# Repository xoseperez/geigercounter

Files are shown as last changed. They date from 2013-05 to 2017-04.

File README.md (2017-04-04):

# Geiger Counter

Geiger counter based on the [Geiger Counter Radiation Detector DIY Kit](http://www.rhelectronics.net/store/radiation-detector-geiger-counter-diy-kit-second-edition.html "Geiger Counter Radiation Detector DIY Kit") from [Radio Hobby Store](http://www.rhelectronics.net/store/ "RH electronics store").

You can read about this project in my blog: [Geiger Counter](http://tinkerman.eldiariblau.net/geiger-counter/ "Geiger Counter").

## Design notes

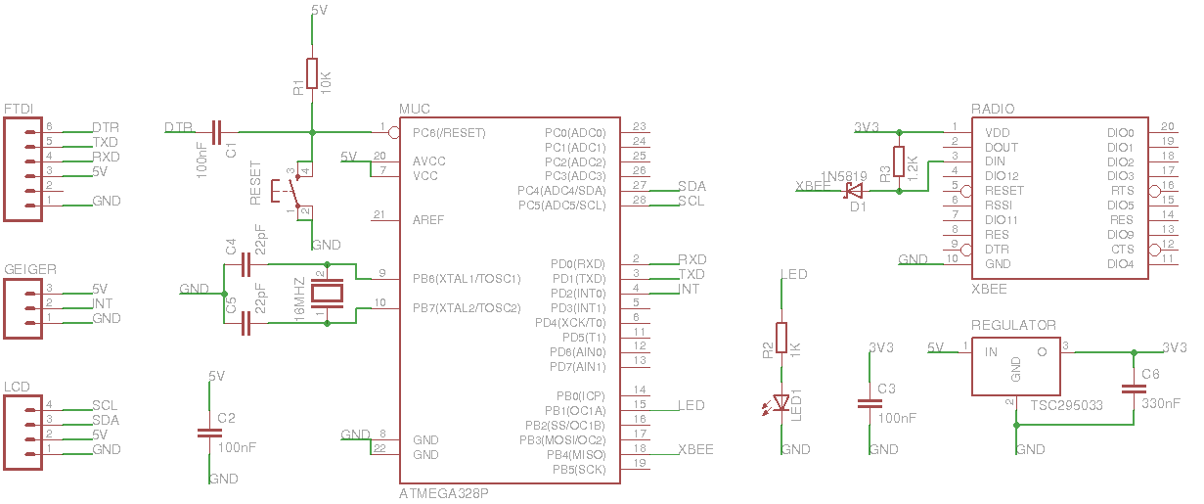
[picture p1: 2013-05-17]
schema/schema.png

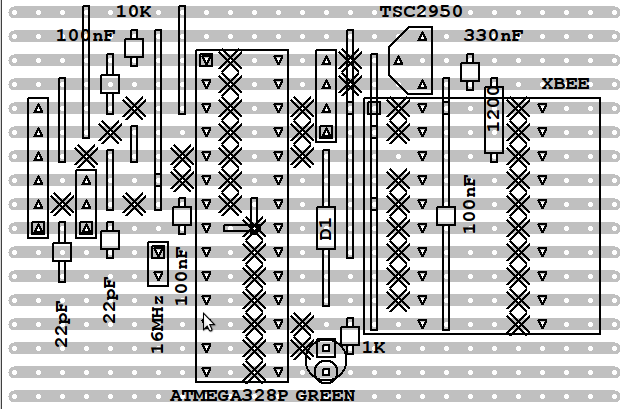
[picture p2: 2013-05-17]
schema/stripboard.png

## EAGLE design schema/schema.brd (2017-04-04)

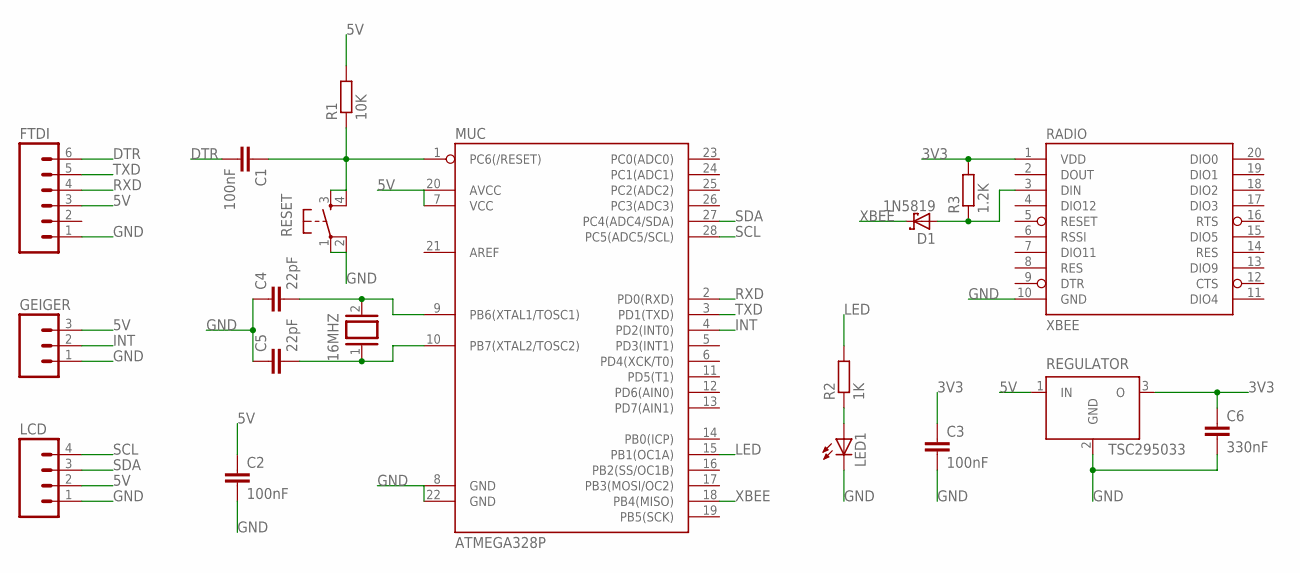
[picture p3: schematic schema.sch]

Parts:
16MHZ: XTAL/S; QS
C1, C2, C3: 100nF; C025-025X050
C4, C5: 22pF; C025-025X050
C6: 330nF; C025-025X050
D1: 1N5819; DO41-7.6
FTDI: M06SIP; 1X06
GEIGER: M03PTH; 1X03
LCD: M04PTH; 1X04
LED1: LED3MM
MUC: ATMEGA328P; DIL28-3
R1: 10K; 0207/10
R2: 1K; 0207/10
R3: 1.2K; 0207/10
RADIO: XBEE; XBEE-1
REGULATOR: TSC295033; TO92
RESET: TAC_SWITCHPTH; TACTILE-PTH

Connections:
3V3: C3.1, C6.1, R3.2, RADIO.1 (VDD), REGULATOR.3 (O)
5V: C2.1, FTDI.3, GEIGER.3, LCD.2, MUC.7 (VCC), MUC.20 (AVCC), R1.2, REGULATOR.1 (IN)
DTR: C1.2, FTDI.6
GND: C2.2, C3.2, C4.1, C5.1, C6.2, FTDI.1, GEIGER.1, LCD.1, LED1.K (C), MUC.8 (GND), MUC.22 (GND), RADIO.10 (GND), REGULATOR.2 (GND), RESET.1, RESET.2
INT: GEIGER.2, MUC.4 (PD2(INT0))
LED: MUC.15 (PB1(OC1A)), R2.2
unnamed: C1.1, MUC.1 (PC6(/RESET)), R1.1, RESET.3, RESET.4
unnamed: 16MHZ.2, C4.2, MUC.9 (PB6(XTAL1/TOSC1))
unnamed: 16MHZ.1, C5.2, MUC.10 (PB7(XTAL2/TOSC2))
unnamed: D1.A, R3.1, RADIO.3 (DIN)
unnamed: LED1.A, R2.1
RXD: FTDI.4, MUC.2 (PD0(RXD))
SCL: LCD.4, MUC.28 (PC5(ADC5/SCL))
SDA: LCD.3, MUC.27 (PC4(ADC4/SDA))
TXD: FTDI.5, MUC.3 (PD1(TXD))
XBEE: D1.C, MUC.18 (PB4(MISO))

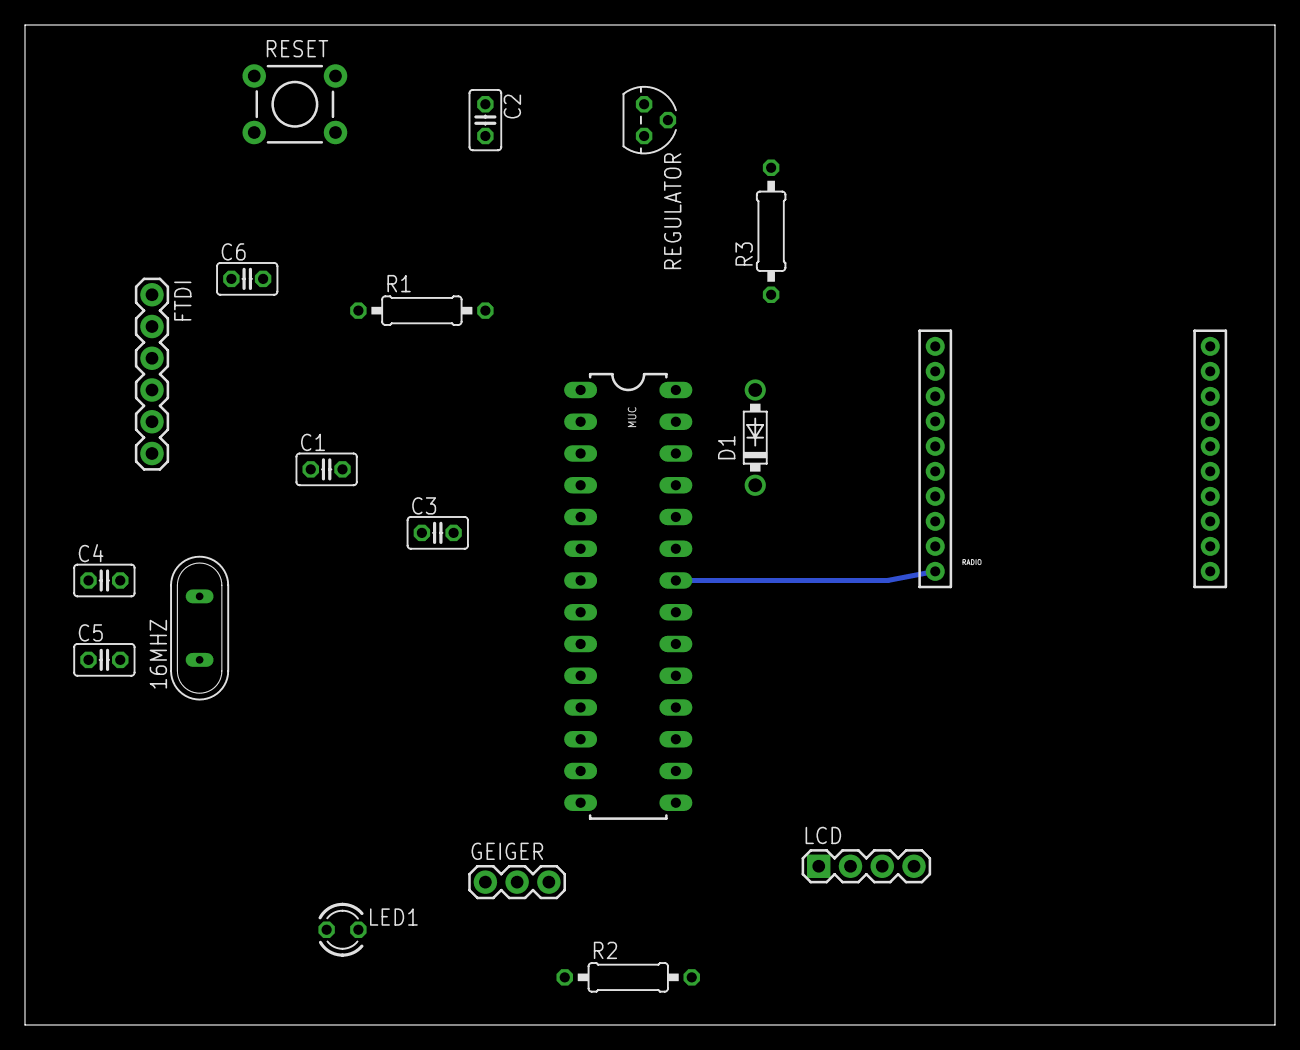
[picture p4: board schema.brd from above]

Board: 2 copper layers, 100.0 x 80.0 mm, 19 parts (0 on the bottom side), 16 nets.

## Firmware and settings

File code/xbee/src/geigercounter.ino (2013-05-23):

/*

  Geiger-Muller Counter
  Copyright (C) 2013 by Xose Pérez <xose dot perez at gmail dot com>

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
*/

#include <SoftwareSerial.h>
#include <Wire.h>
#include <LiquidCrystal_I2C.h>

// ===========================================
// Configuration
// ===========================================

// pin definitions
#define GEIGER_INTERRUPT 0
#define DEBUG_PIN 9
#define XBEE_PIN 12

// count data for a whole minute (60000 milliseconds)
// split into 10 chunks of 6 seconds each
#define PERIOD_LENGTH 60000
#define UPDATES_PER_PERIOD 10

// conversion factor from CPM to uSv/h based on data from Libellium for the SBM-20 tube
// http://www.cooking-hacks.com/index.php/documentation/tutorials/geiger-counter-arduino-radiation-sensor-board
#define CPM_TO_USVH 0.0057


// ===========================================
// Globals
// ===========================================

// pulses in the current subperiod
volatile unsigned long pulses = 0;

// stores the pulses for a set of 6 seconds periods
unsigned long ring[UPDATES_PER_PERIOD] = {0};

// pointer to the next cell in the ring to update
byte pointer = 0;

// keeps the sum of counts for the ring
unsigned long cpm = 0;

// time of the next update
unsigned long next_update = 0;

// during the first minute after a reset, the display shows a "warming up" message
boolean warmup = true;

// serial link to the radio
SoftwareSerial xbee(0, XBEE_PIN);

// LCD management
// Thanks to Riva for pointing out the wrong pin order
// http://arduino.cc/forum/index.php?topic=164722.0
// 0 -> RS
// 1 -> RW
// 2 -> EN
// 3 -> LED
// 4- > D4
// 5 -> D5
// 6 -> D6
// 7 -> D7
//
// Constructor with backlight control
// LiquidCrystal_I2C(uint8_t lcd_Addr, uint8_t En, uint8_t Rw, uint8_t Rs,.
//                  uint8_t d4, uint8_t d5, uint8_t d6, uint8_t d7,
//                  uint8_t backlighPin, t_backlighPol pol);
LiquidCrystal_I2C lcd(0x20, 2, 1, 0, 4, 5, 6, 7, 3, POSITIVE);

// ===========================================
// Interrupt routines
// ===========================================

/**
 * pulse
 *
 * Called on every LOW-to-HIGH transition on the 
 * GEIGER_INTERRUPT pin. It updates the current count.
 *
 * @return void
 */
void pulse() {
    ++pulses;
}

// ===========================================
// Methods
// ===========================================

/**
 * update
 *
 * Updates the ring and CPM count.
 * Shows the results on the LCD and sends them through radio every minute.
 *
 * @return void
 */
void update() {

    // calculate the moving sum of counts
    cpm = cpm - ring[pointer] + pulses;

    // store the current period value
    ring[pointer] = pulses;

    // reset the interrupt counter
    pulses = 0;

    // move the pointer to the next position in the ring
    pointer = (pointer + 1) % UPDATES_PER_PERIOD;

    // calculate the uSv/h 
    float usvh = cpm * CPM_TO_USVH;

    // show data in LCD
    if (warmup) {

        lcd.setCursor(0, 1);
        lcd.print(cpm, DEC);

    } else {

        lcd.clear();
        lcd.print(F("CPM:   "));
        lcd.print(cpm, DEC);
        lcd.setCursor(0, 1);
        lcd.print(F("uSv/h: "));
        lcd.print(usvh, 3);

    }

    // send data through radio everytime the ring loops back
    if (pointer == 0) {

        digitalWrite(DEBUG_PIN, HIGH);

        xbee.print(F("cpm:"));
        xbee.println(cpm, DEC);
        delay(20);
        xbee.print(F("usvh:"));
        xbee.println(usvh, 3);
        delay(20);

        digitalWrite(DEBUG_PIN, LOW);

        // finish the warmup after the first full period
        warmup = false;

    }

}

/**
 * setup
 *
 * Configures pins, LCD and XBee. Sets up interrups.
 *
 * @return void
 */
void setup() {

    pinMode(DEBUG_PIN, OUTPUT);
    digitalWrite(DEBUG_PIN, LOW);

    // initilize LCD and XBEE
    lcd.begin(16,2);
    lcd.setBacklight(BACKLIGHT_ON);
    xbee.begin(9600);
    delay(500);

    // show warmup message
    lcd.home();
    lcd.print(F("Warming up..."));

    // send welcome message
    xbee.println(F("status:1"));

    // allow pulse to trigger interrupt on rising
    attachInterrupt(GEIGER_INTERRUPT, pulse, RISING);

    // calculate next update
    next_update = millis() + PERIOD_LENGTH / UPDATES_PER_PERIOD;

}

/**
 * loop
 *
 * Continuously checks for the next update time.
 *
 * @return void
 */
void loop() {

    // check if I have to update the info
    if (millis() > next_update) {
        next_update = millis() + PERIOD_LENGTH / UPDATES_PER_PERIOD;
        update();
    }

}

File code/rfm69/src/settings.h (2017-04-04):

// -----------------------------------------------------------------------------
// Settings
// -----------------------------------------------------------------------------

// This node ID, should be unique in the same network
#define NODEID              13

// Gateway ID that will receive the messages from this node
#define GATEWAYID           1

// Network ID, only nodes from the same network see each other
#define NETWORKID           164

// Frequency of the radio, should match your radio module and
// comply with your country legislation
#define FREQUENCY           RF69_868MHZ

// Encription key, shared between the node and the gateway
#define ENCRYPTKEY          "fibonacci0123456"

// If you are using a RFM69HW or RFM69HCW module set this to 1 to
// transmitt to extra power (and extra battery drainage)
#define IS_RFM69HW          0

// Set the target RSSI for Auto Transmission Control feature.
// The module will modify it's transmitting power to match this
// value (relies on ACK packets to check the RSSI the gateway has seen).
#define ATC_RSSI            -75

// Comment to stop sending debug messages to serial console
#define DEBUG

// Define serial baudrate
#define SERIAL_BAUD         115200

// Various PIN definitions
#define LED_PIN             9
#define COUNTER_PIN         3

// Update counts every 6 seconds
#define UPDATE_INTERVAL     6000

// Ring size is 10 positions,
// when it overflows a message is sent via radio,
// that means every 60 seconds
#define RING_SIZE           10

// After an interrupt, wait this amount of milliseconds for
// signal to stabilize (avoid bouncing).
#define DEBOUNCE_INTERVAL   5

// Flash LED for this amount of milliseconds after every message sent
#define NOTIFICATION_TIME   5

// Conversion factor from CPM to uSv/h based on data from Libellium for the SBM-20 tube
// http://www.cooking-hacks.com/index.php/documentation/tutorials/geiger-counter-arduino-radiation-sensor-board
#define CPM_TO_USVH         0.0057

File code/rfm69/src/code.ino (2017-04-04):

 /*

Moteino Geiger Counter

Copyright (C) 2017 by Xose Pérez <xose dot perez at gmail dot com>

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
*/

#include "settings.h"
#include <RFM69Manager.h>
#include <Wire.h>
#include <LiquidCrystal_I2C.h>

// -----------------------------------------------------------------------------
// Globals
// -----------------------------------------------------------------------------

RFM69Manager radio;
volatile boolean flag = false;
volatile unsigned long pulses = 0;
unsigned long ring[RING_SIZE] = {0};
byte ring_pointer = 0;
unsigned long cpm = 0;
boolean warmup = true;

LiquidCrystal_I2C lcd(0x20, 16, 2);

// -----------------------------------------------------------------------------
// Hardware
// -----------------------------------------------------------------------------

void countEvent() {
    ++pulses;
}

void blink(byte times, byte mseconds) {
    pinMode(LED_PIN, OUTPUT);
    for (byte i=0; i<times; i++) {
        if (i>0) delay(mseconds);
        digitalWrite(LED_PIN, HIGH);
        delay(mseconds);
        digitalWrite(LED_PIN, LOW);
    }
}

void i2cScan() {

    unsigned char address;
    unsigned char error;
    int nDevices = 0;
    char buffer[40];

    for (address = 1; address < 127; address++) {

        Wire.beginTransmission(address);
        error = Wire.endTransmission();

        if (error == 0) {
            sprintf(buffer, "[I2C] Device found at address 0x%02X", address);
            Serial.println(buffer);
            nDevices++;
        }

    }

    if (nDevices == 0) Serial.println("[I2C] No devices found");

}

void hardwareSetup() {

    Serial.begin(SERIAL_BAUD);
    pinMode(LED_PIN, OUTPUT);
    attachInterrupt(digitalPinToInterrupt(COUNTER_PIN), countEvent, RISING);

    Wire.begin();
    i2cScan();
    lcd.init();
    lcd.backlight();

    // show warmup message
    lcd.home();
    lcd.print(F("Warming up..."));

}

/**
 * update
 *
 * Updates the ring and CPM count.
 * Shows the results on the LCD and sends them through radio every minute.
 *
 * @return void
 */
void update() {

    // calculate the moving sum of pulses
    cpm = cpm - ring[ring_pointer] + pulses;

    // store the current period value
    ring[ring_pointer] = pulses;

    // reset the interrupt counter
    pulses = 0;

    // move the pointer to the next position in the ring
    ring_pointer = (ring_pointer + 1) % RING_SIZE;

    // show data in LCD
    if (warmup) {

        lcd.setCursor(0, 1);
        lcd.print(cpm, DEC);

    } else {

        // calculate the uSv/h
        float usvh = CPM_TO_USVH * cpm;

        lcd.clear();
        lcd.print(F("CPM:   "));
        lcd.print(cpm, DEC);
        lcd.setCursor(0, 1);
        lcd.print(F("uSv/h: "));
        lcd.print(usvh, 3);

    }

    // send data through radio everytime the ring loops back
    if (ring_pointer == 0) {

        // send pulses via radio
        sendValues();

        // notify sending
        blink(1, NOTIFICATION_TIME);

        // finish the warmup after the first full period
        warmup = false;

    }

}

// -----------------------------------------------------------------------------
// RFM69
// -----------------------------------------------------------------------------

void radioSetup() {
    radio.initialize(FREQUENCY, NODEID, NETWORKID, ENCRYPTKEY, GATEWAYID, ATC_RSSI);
    radio.sleep();
}

void sendValues() {

    char buffer[10];

    sprintf(buffer, "%lu", cpm);
    radio.send((char *) "CPM", buffer, (uint8_t) 2);

    float usvh = CPM_TO_USVH * cpm;
    dtostrf(usvh, 8, 3, buffer);
    char * p = buffer;
    while ((unsigned char) *p == ' ') ++p;
    radio.send((char *) "USH", p, (uint8_t) 2);

    radio.sleep();

}

// -----------------------------------------------------------------------------
// Common methods
// -----------------------------------------------------------------------------

void setup() {
    hardwareSetup();
    radioSetup();
}

void loop() {
    static unsigned long last = 0;
    if (millis() - last > UPDATE_INTERVAL) {
        last = millis();
        update();
    }
}

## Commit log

2013-05-08 Using NewLiquidCrystal library interfacing with cheapo I2C LCD module
2013-05-08 Eagle schema
    [schema.sch]
2013-05-08 Small changes in the eagle schema
    [schema.sch]
2013-05-10 Stripboard design and PIN changes
    [schema.sch]
2013-05-10 Bug fix in the eagle schema: replace zener for schottky
    [schema.sch]
2013-05-17 Fix schematics
    [schema.sch]
2017-04-04 Pending changes
    [schema.brd, schema.sch]

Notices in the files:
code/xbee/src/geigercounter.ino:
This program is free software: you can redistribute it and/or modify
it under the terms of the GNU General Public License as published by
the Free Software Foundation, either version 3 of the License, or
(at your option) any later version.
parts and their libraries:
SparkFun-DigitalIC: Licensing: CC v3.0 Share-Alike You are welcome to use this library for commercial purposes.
